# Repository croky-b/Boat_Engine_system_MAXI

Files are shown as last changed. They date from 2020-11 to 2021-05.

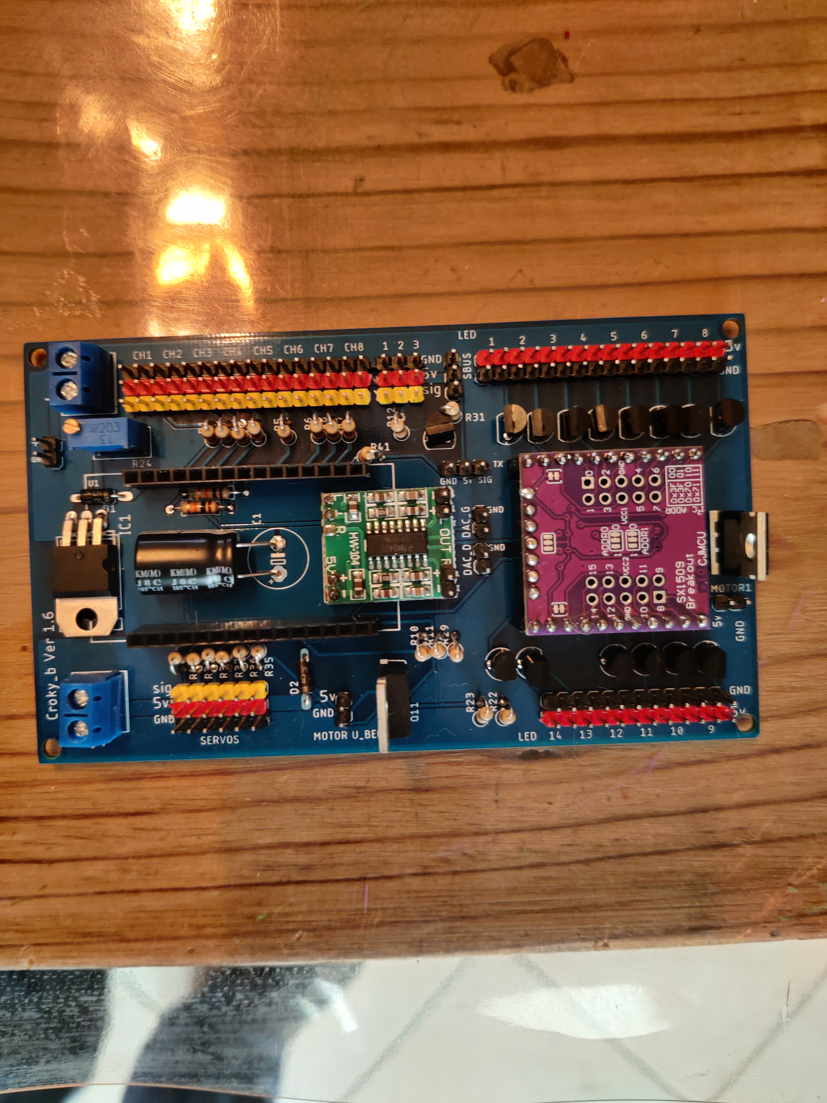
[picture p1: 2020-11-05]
IMG_20201025_121146.jpg

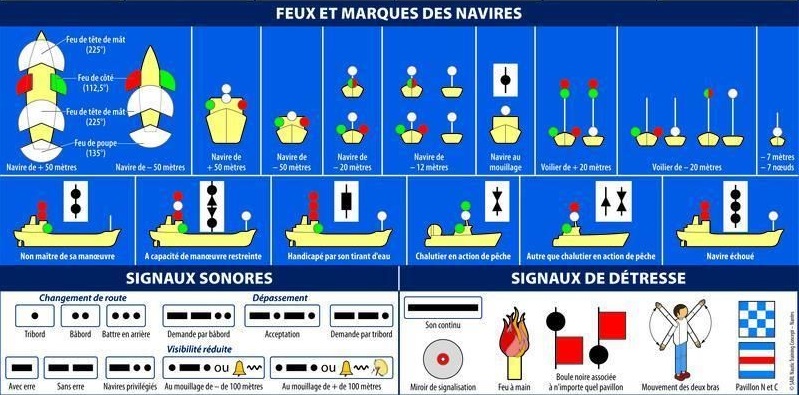
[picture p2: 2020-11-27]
Config 5.7/Fichiers/feux et sons.jpg

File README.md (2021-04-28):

# This is an Arduino RC engine sound & light & Servo controller for ESP32
Adaptation du projet de :https://github.com/TheDIYGuy999/Rc_Engine_Sound_ESP32
pour une utilisation "bateau" 

## Eratta : R29 = 10K 

## Version :
### version 5.7:
fonction special led 
multiswitch 
les fichiers des multiswitch arriveron bientot
### version 5.5:
- Integration des séquences 
### version 5.3:
- Bug sur VOSPER sound fixed 
### version 5.2:
- 
### Version 5.1:
- Configuration par HTML
### Version 5.0:
-

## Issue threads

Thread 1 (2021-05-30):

Config and error at Compiler

aexeler, 2021-05-30:
Hi Croky-b,
i found yout great Project and will build it.
ill try to understand your Config tool, so first i test it with no Action or LED fuction.
So i only select in the Generalconfig:

Son Moteur: PT Boat
AIR STARTER yes
Engine ON/OFF
Manuel  7 Ch
Start SounBoard Sound: Corne de brume

rest as default

Create Setup file and save, copy the 1-Setup.h to the Project folder and compile:

get this error

Boat_Engine_system_MAXI\sounds\boat\AuxSound\Long_blast1.h:1:1: error: stray '\357' in program

Boat_Engine_system_MAXI\sounds\boat\AuxSound\Long_blast1.h:1:1: error: stray '\273' in program

Boat_Engine_system_MAXI\sounds\boat\AuxSound\Long_blast1.h:1:1: error: stray '\277' in program

exit status 1

Find out that i have change in the Action 3 (not selectet) the "Corne brume 1" to "Corne brume 2" and the compile works!
So Sound up at Start and engine runs!!!

Try some Action, but now any new Action (Sound) e.g. Cloche will work.

May you can explane me your Config-Tool.
Best Regards
Andreas Exeler

PS, i need a huge (5000PS) Diesel Engine Sound (i have a Happy Hunter from Robbe)
The TheDIYGuy999, Martin, has told me to look at your Project, because i have no Trucks.

croky-b, 2021-05-30:
Hello Send me your setup file CédricLe 30 mai 2021 13:18, aexeler ***@***.***> a écrit :
Hi Croky-b,
i found yout great Project and will build it.
ill try to understand your Config tool, so first i test it with no Action or LED fuction.
So i only select in the Generalconfig:
Son Moteur: PT Boat
AIR STARTER yes
Engine ON/OFF
Manuel  7 Ch
Start SounBoard Sound: Corne de brume
rest as default
Create Setup file and save, copy the 1-Setup.h to the Project folder and compile:
get this error
Boat_Engine_system_MAXI\sounds\boat\AuxSound\Long_blast1.h:1:1: error: stray '\357' in program
Boat_Engine_system_MAXI\sounds\boat\AuxSound\Long_blast1.h:1:1: error: stray '\273' in program
Boat_Engine_system_MAXI\sounds\boat\AuxSound\Long_blast1.h:1:1: error: stray '\277' in program
exit status 1
Find out that i have change in the Action 3 (not selectet) the "Corne brume 1" to "Corne brume 2" and the compile works!
So Sound up at Start and engine runs!!!
Try some Action, but now any new Action (Sound) e.g. Cloche will work.
May you can explane me your Config-Tool.
Best Regards
Andreas Exeler
PS, i need a huge (5000PS) Diesel Engine Sound (i have a Happy Hunter from Robbe)
The TheDIYGuy999, Martin, has told me to look at your Project, because i have no Trucks.

—You are receiving this because you are subscribed to this thread.Reply to this email directly, view it on GitHub, or unsubscribe.

croky-b, 2021-05-30:
Boat_Engine_system_MAXI\sounds\boat\AuxSound\Long_blast1.h:1:1: error: stray '\357' in program

For this check if the sound is in the folder

croky-b, 2021-05-30:
Contact me on my email

aexeler, 2021-05-30:
Hi,
i am sorry, but i cant see your email, sorry.
[Setup.txt](https://github.com/croky-b/Boat_Engine_system_MAXI/files/6566768/Setup.txt)
The long_blast1.h is in the folder.

What kind of Multiswitch you prefer?
Will this work?
[https://shop.cp-elektronik.de/Sender-erweitern/16-Kanal-Encoder-Nautic-Schaltbaustein-MC-15-u-ae::105.html](url)
( i have a MC-19 with Spektrum 2.4 GHz Transmitter)

Greets and thanks for help!
Andreas

croky-b, 2021-05-30:
Can you sens me the setup from Arduino, It s the recap fileLe 30 mai 2021 21:07, aexeler ***@***.***> a écrit :
Hi,
i am sorry, but i cant see your email, sorry.
Setup.txt
The long_blast1.h is in the folder.
What kind of Multiswitch you prefer?
Will this work?
https://shop.cp-elektronik.de/Sender-erweitern/16-Kanal-Encoder-Nautic-Schaltbaustein-MC-15-u-ae::105.html
( i have a MC-19 with Spektrum 2.4 GHz Transmitter)
Greets and thanks for help!
Andreas

—You are receiving this because you commented.Reply to this email directly, view it on GitHub, or unsubscribe.

aexeler, 2021-05-30:
Hi,
The setup.txt in my last post is the recap file.
Thanks for help.
Andreas

croky-b, 2021-05-30:
For the multi Switch http://www.bricodx.fr/articles/3-electronique/16-commande-multifonctions/The type 1 us for the simple versionThe type 2 is for the optocoupler versionLe 30 mai 2021 21:07, aexeler ***@***.***> a écrit :
Hi,
i am sorry, but i cant see your email, sorry.
Setup.txt
The long_blast1.h is in the folder.
What kind of Multiswitch you prefer?
Will this work?
https://shop.cp-elektronik.de/Sender-erweitern/16-Kanal-Encoder-Nautic-Schaltbaustein-MC-15-u-ae::105.html
( i have a MC-19 with Spektrum 2.4 GHz Transmitter)
Greets and thanks for help!
Andreas

—You are receiving this because you commented.Reply to this email directly, view it on GitHub, or unsubscribe.

croky-b, 2021-05-30:
Yes it is the setup recapSend me  setup.h Sorry for m'y bad englishCédricLe 30 mai 2021 21:07, aexeler ***@***.***> a écrit :
Hi,
i am sorry, but i cant see your email, sorry.
Setup.txt
The long_blast1.h is in the folder.
What kind of Multiswitch you prefer?
Will this work?
https://shop.cp-elektronik.de/Sender-erweitern/16-Kanal-Encoder-Nautic-Schaltbaustein-MC-15-u-ae::105.html
( i have a MC-19 with Spektrum 2.4 GHz Transmitter)
Greets and thanks for help!
Andreas

—You are receiving this because you commented.Reply to this email directly, view it on GitHub, or unsubscribe.

croky-b, 2021-05-30:
The stray error is due to a bad character but at home I do not have itI use the Arduino version 1.8.12Le 30 mai 2021 21:07, aexeler ***@***.***> a écrit :
Hi,
i am sorry, but i cant see your email, sorry.
Setup.txt
The long_blast1.h is in the folder.
What kind of Multiswitch you prefer?
Will this work?
https://shop.cp-elektronik.de/Sender-erweitern/16-Kanal-Encoder-Nautic-Schaltbaustein-MC-15-u-ae::105.html
( i have a MC-19 with Spektrum 2.4 GHz Transmitter)
Greets and thanks for help!
Andreas

—You are receiving this because you commented.Reply to this email directly, view it on GitHub, or unsubscribe.

aexeler, 2021-05-30:
Hi,
my english is not better. ;-)
hier the 1-setup.h

Will the type 2 with optocoupler work with your Boat Engine System?

Greets
Andreas

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

aexeler, 2021-05-30:
cant attach  a .h file, so i rename the .h to .txt
the 1-Setup.txt is the 1-Setup.h
[1-Setup.txt](https://github.com/croky-b/Boat_Engine_system_MAXI/files/6566816/1-Setup.txt)

croky-b, 2021-05-30:
define ACTION3CH 0
No Channel assigned to action 3
The action 3 it is for the fog mode

croky-b, 2021-05-30:
The fog mode , played sound automatically
Example: the bell when the anchor is at the bottom

croky-b, 2021-05-30:
Will the type 2 with optocoupler work with your Boat Engine System?

Yes i use it on my futaba fc16
I'll upload the modified code for my project

aexeler, 2021-05-30:
Ah, ok.
So i have to use a other action and try it.
The type 2 with optocoupler on bricodx will work with your system?
Greets
Andreas

aexeler, 2021-05-30:
Ok, i will have a look at the type 2 for my mc19
Thanks

aexeler, 2021-05-30:
Need i Chance the code for the Arduino Mini in the Transmitter?

croky-b, 2021-05-30:
Yes a litle. It is possible to have 14 or 16 Channel to one Channel

And the pulse start to 2

croky-b, 2021-05-30:
I fixed the fog mode bell bug
That's why the bell rings at home

aexeler, 2021-05-30:
have you the code for the Transmitter?
i am not sure that i can change it right.

croky-b, 2021-05-30:
I upload tomorrow the code

aexeler, 2021-05-30:
Thanks,
Will try tomorrow a new Version with more Actions on the Controller

croky-b, 2021-05-30:
Action 1: special lamps for fishing vessels (red on white lights)

Action 2 for anchor

Action 3 fog mode

Action 4 manoeuvre
3 sound for reversing
2 for left

Action 5 warning
Overtaking from the left

Action 6 machine gun
Action 7 cannon

Action 8 alarm

Action 9 night mode

Action 10 lighting of lamps

Action 11
Plays a sound
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
croky-b, 2022-03-30:
I fixed the bug of shorthorn1

croky-b, 2022-03-30:
changes  PULSWIDTH_DEBUG
by that one

#ifdef PULSWIDTH_DEBUG
if (millis() - printMillis > 300) // Print the data every 300ms
{
printMillis = millis();
if (Init){
Serial.print("SOUNDBOARD START = OK");}
else{Serial.print("SOUNDBOARD START = WAIT!!");}
Serial.println(" ");
if(engineState==0){Serial.print("Motor = OFF");}

else if (engineState==1){Serial.print("Motor = AIRSTART");}
else if (engineState==2){Serial.print("Motor = START");}
else if (engineState==3){Serial.print("Motor = ON");}
else if (engineState==4){Serial.print("Motor = SHUTDOWN");}
Serial.println(" ");

Serial.print("pulseWidth[MULTI_1_CH-1] :");
Serial.println(pulseWidth[MULTI_1_CH-1]);

Serial.print("Act1 :");
Serial.println(Act1);

Serial.print("Act1 :");
Serial.println(Act2);

Serial.print("Act3 :");
Serial.println(Act3);

Serial.print("Act4 :");
Serial.println(Act4);

Serial.print("Act5 :");
Serial.println(Act5);

Serial.print("Act6 :");
Serial.println(Act6);

Serial.print("Act7 :");
Serial.println(Act7);

Serial.print("Act8 :");
Serial.println(Act8);

Serial.print("Fishing :");
Serial.println(Fishing);

Serial.print("DIRECTION :");
Serial.println(pulseWidth[steeringCh - 1]);

Serial.print("PROFONDEUR :");
Serial.println(pulseWidth[ElCh - 1]);

Serial.print("GAZ :");
Serial.println(pulseWidth[thrustCh - 1]);

Serial.print("AILLERONS :");
Serial.println(pulseWidth[AilCh-1]);
Serial.print("CH5 :");
Serial.println(pulseWidth[4]);
Serial.print("CH6 :");
Serial.println(pulseWidth[5]);
Serial.print("CH7 :");
Serial.println(pulseWidth[6]);
Serial.print("CH8 :");
Serial.println(pulseWidth[7]);
Serial.print("CH9 :");
Serial.println(pulseWidth[8]);
Serial.print("CH10 :");
Serial.println(pulseWidth[9]);
Serial.print("CH11 :");
Serial.println(pulseWidth[10]);
Serial.print("CH14 :");
Serial.println(pulseWidth[13]);

Serial.println("");

}
#endif

croky-b, 2022-03-30:
When you started the engine?
If yes
Use the action 9 it allows to light the leds chosen when the engine has started

aexeler, 2022-03-30:
Hi,
no Action is set, only the gerneralconfig is set,
try to compile but get error:

Sound:3136:0: error: unterminated #ifdef
  #ifdef ACTION11A_ENABLE
 ^
exit status 1
unterminated #ifdef

croky-b, 2022-03-30:
I am fixing quite a few errors but I lost a lot of files due to pc crash

aexeler, 2022-03-30:
oh,
thats bad,
i am sorry, so many work for me.
take the time as you need, no problem
thanks for help!

croky-b, 2022-03-30:
This weekend I will make a configuration that works at home and I transmit it to you

aexeler, 2022-03-31:
that would be great!

aexeler, 2022-04-01:
Hi,
i try some diff. settings and found some "Bugs".
The Channel for the Sequence1 and 2 are in the save file the same (eg. ch10), but in the html are set on Ch9 and 10.
The Action9 LED will work (so the SX1509 is online!) when the Engine start manual and the Action 9 is setup with an switch.
The led came on the engine start but not on the selectet switch.
May it helps.

Greets
Andreas

croky-b, 2022-04-01:
Ok I fixed the sequence bug
Good news that the sx1509 works
There must be a bug in the multiswitch code
I found some for type1, I'm trying to fix them

aexeler, 2022-04-01:
Hi,

top, thanks!

Is there a change to get an “import” for the config-file in the html-configurator?

So, every new open, I must setup all pages to generate a new config.

(at the moment I test a lot)

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

croky-b, 2022-04-01:
#include "XT_DAC_Audio.h"

//______________________________________________________________________________
//-------------------------------VOLUME----------------------------------
//_______________________________________________________________________________

#define ANCOR_VOL 127
#define SHORT_VOL 127
#define LONG_VOL 127
#define GUN_VOL 127
#define AAGUN_VOL 127
#define LONG_VOL 127
#define ALARM1_VOL 127
#define ALARM2_VOL 127
#define BELL_VOL 127
#define SEAGULL_VOL 127
#define AMBIENT_VOL 127
#define TWELVE1_VOL 127
#define TWELVE2_VOL 127
#define TWELVE3_VOL 127
#define ELEVEN1_VOL 127
#define ELEVEN2_VOL 127
#define ELEVEN3_VOL 127
#define
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

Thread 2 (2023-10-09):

Compilation Problem.

chris27940, 2023-10-09:
Hi, good evening.
I try to finish my boat engine system but i have one error when i try to compile the sketch : text section exceeds available space in board Le croquis utilise 2203490 octets (168%) de l'espace de stockage de programmes. Le maximum est de 1310720 octets;
Do you known what the problem with the sketch ? Do i have to change board config ?
Thanks. Regards, Christophe.

croky-b, 2023-10-09:
hi
in arduino ide
TOOL>>partition Scheme>>>Hudge app

chris27940, 2023-10-21:
Thanks a lot. It's working now.

chris27940, 2023-10-21:
Good morning, i have another question. Before compliling, i have to open Config_Croky_b and save only setup file ? What is the fonction "create INO file" ? Thanks.

croky-b, 2023-10-21:
Créât ino file is for the servo sequencer

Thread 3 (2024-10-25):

Broken program ,pleas Help

paegas123, 2024-10-25:
Hello, I'm trying to start this cool project, unfortunately I'm not succeeding at all. The program is normally compiled and uploaded to the ESP32. I have only the amplifier connected to PIO25,26 and the input from the receiver to PIO14 as throttle control. After uploading the ESP32 firmware, it does nothing and does not respond. It can be seen on the serial monitor that it is not doing anything. That is, during HW restart, it will print the restart log, but nothing else. There is no sound coming from the speaker even when the gas is applied. Engine start is set to AUTO. In my opinion, in ESP32 the program won't run at all for some reason. The ESP32 is brand new and works normally with another project. Please help

croky-b, 2025-01-27:
sorry for the late reply, I didn't get a notification

i realized that the code was only compatible with version 1.0.5 of expressif
system in the esp32 card manager, already do a test like that

it's been a long time since i worked on this code, i forgot a lot of things about how it works, i hope this will solve your problem

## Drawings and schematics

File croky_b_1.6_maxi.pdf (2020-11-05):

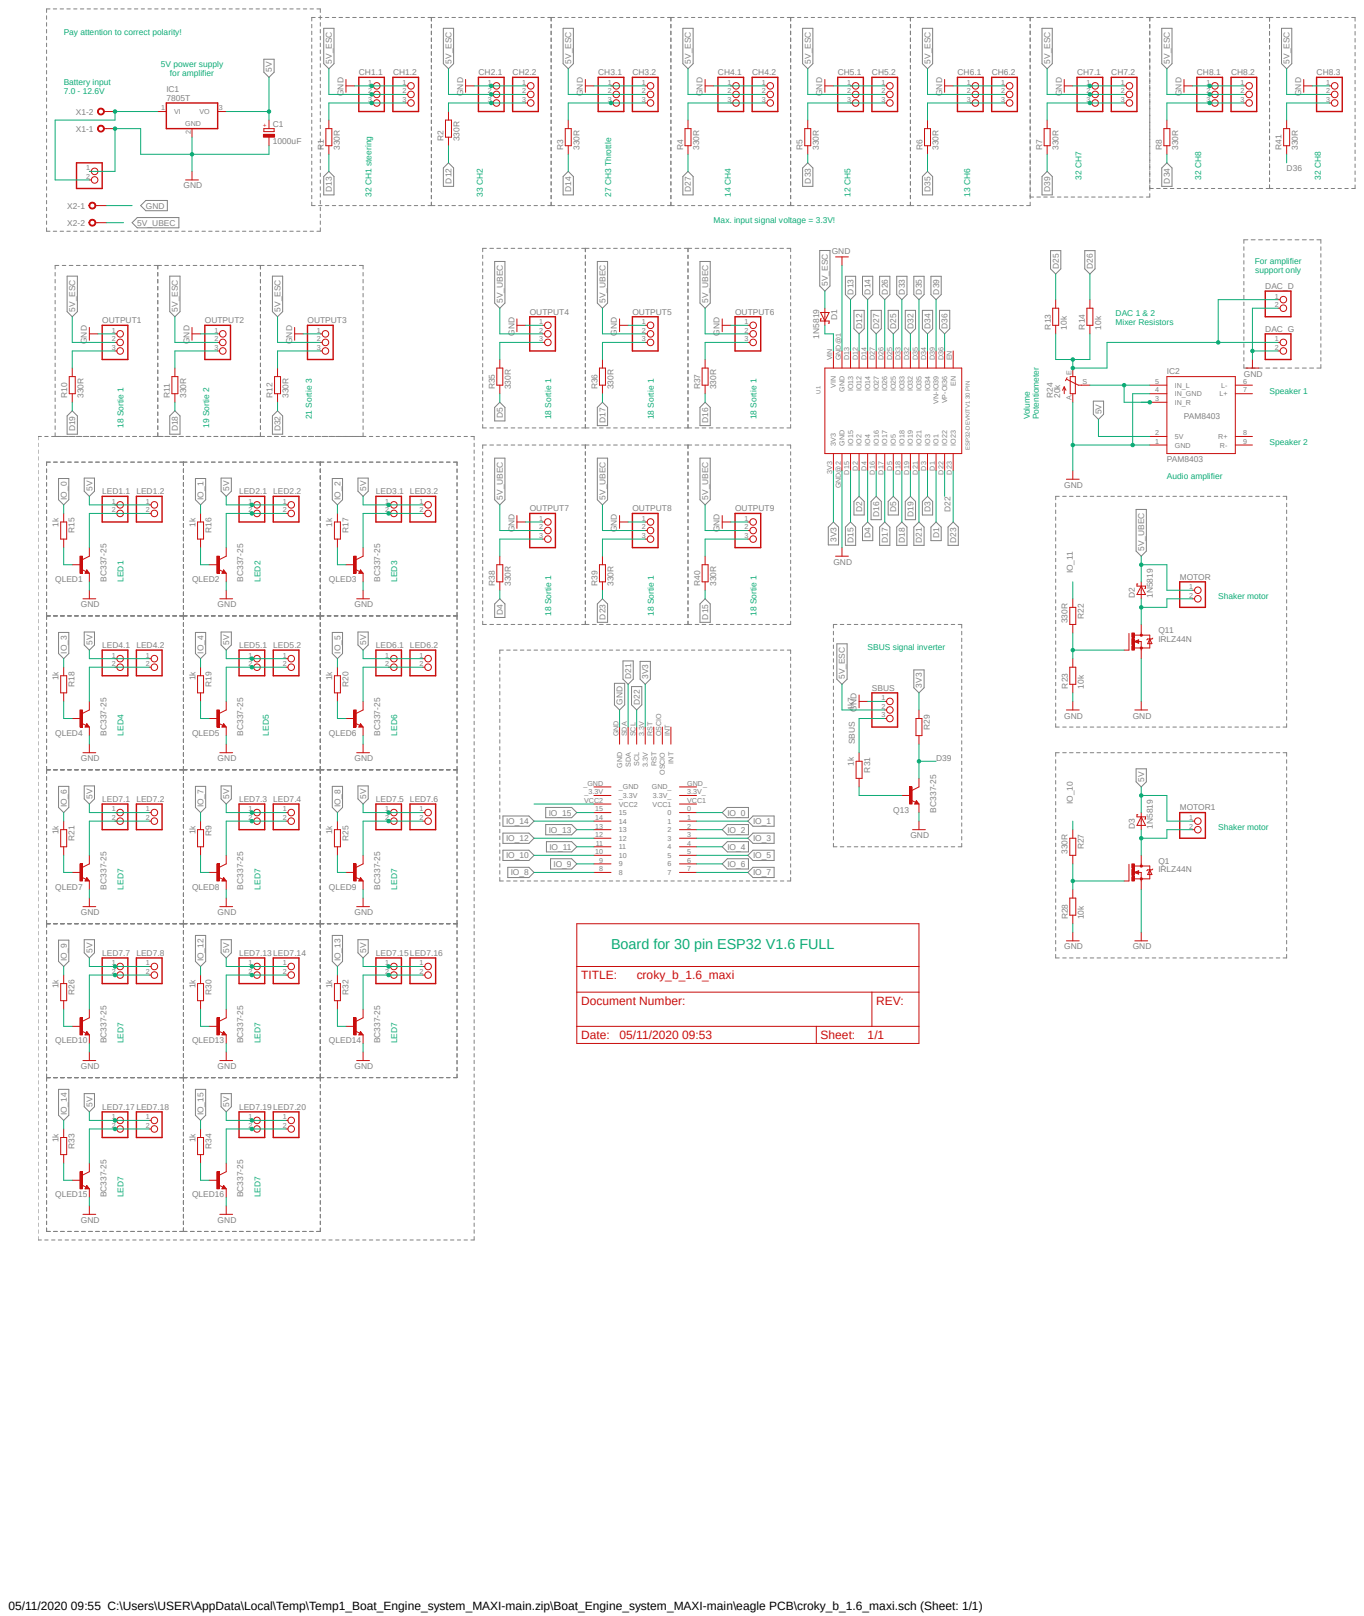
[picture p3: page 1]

Pay attention to correct polarity!

Max. input signal voltage = 3.3V!

IO23 D23 EN EN VP-OI36 D36 VN-IO39 D39 IO34 D34 IO35 D35 IO32 D32 IO33 D33 IO25 D25 IO26 D26 IO27 D27 IO14 D14 IO12 D12 IO13 D13 GND GND@1 VIN VIN GND GND@2

Board for 30 pin ESP32 V1.6 FULL

Document Number: | REV:

Date: 05/11/2020 09:53 | Sheet: 1/1

05/11/2020 09:55 C:\Users\USER\AppData\Local\Temp\Temp1_Boat_Engine_system_MAXI-main.zip\Boat_Engine_system_MAXI-main\eagle PCB\croky_b_1.6_maxi.sch (Sheet: 1/1)

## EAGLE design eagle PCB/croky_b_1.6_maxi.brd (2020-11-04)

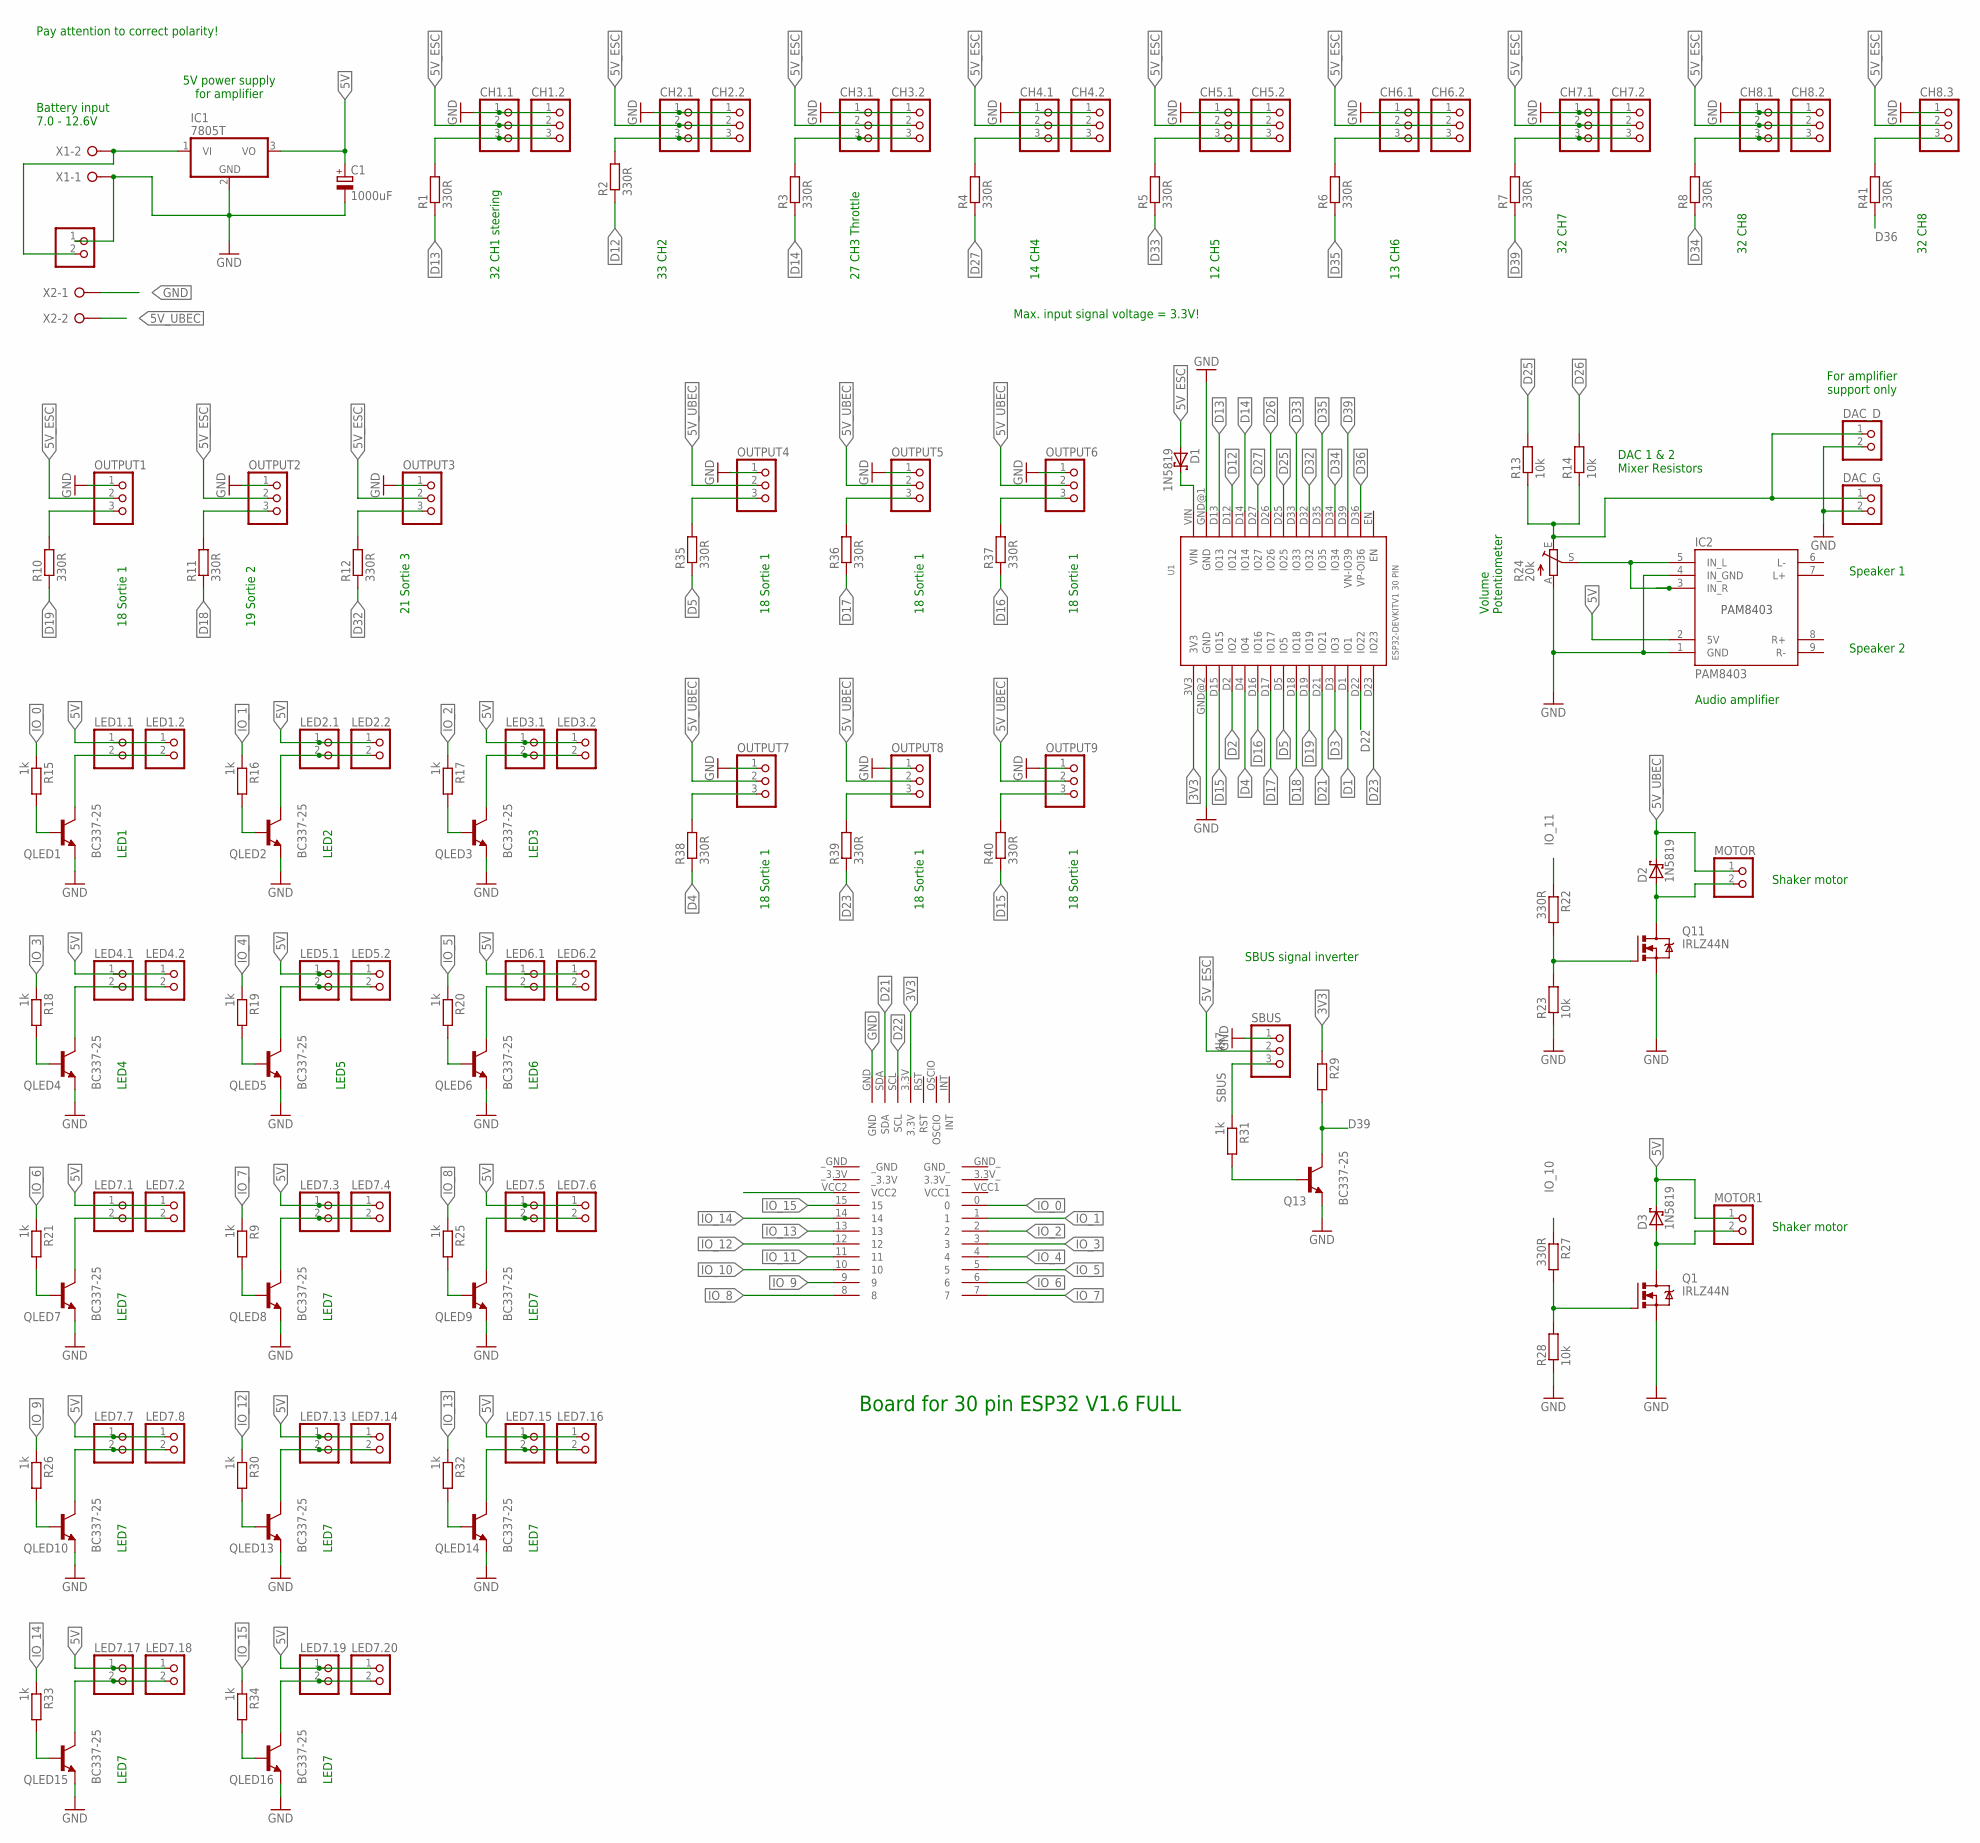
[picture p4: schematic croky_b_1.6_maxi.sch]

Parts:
C1: 1000uF; E5-10,5
CH1.1, CH1.2, CH2.1, CH2.2, CH3.1, CH3.2, CH4.1, CH4.2, CH5.1, CH5.2, CH6.1, CH6.2, CH7.1, CH7.2, CH8.1, CH8.2, CH8.3: PINHD-1X3; 1X03
D1, D2, D3: 1N5819; DO35-7
DAC_D: PINHD-1X2; 1X02
DAC_G: PINHD-1X2; 1X02
IC1: 7805T; TO220H
IC2: PAM8403
LED1.1, LED1.2, LED2.1, LED2.2, LED3.1, LED3.2, LED4.1, LED4.2, LED5.1, LED5.2, LED6.1, LED6.2, LED7.1, LED7.2, LED7.3, LED7.4, LED7.5, LED7.6, LED7.7, LED7.8, LED7.13, LED7.14, LED7.15, LED7.16, LED7.17, LED7.18, LED7.19, LED7.20: PINHD-1X2; 1X02
MOTOR, MOTOR1, MOTOR2: PINHD-1X2; 1X02
OUTPUT1, OUTPUT2, OUTPUT3, OUTPUT4, OUTPUT5, OUTPUT6, OUTPUT7, OUTPUT8, OUTPUT9: PINHD-1X3; 1X03
Q1, Q11: IRLZ44N; TO220BV
Q13: BC337-25; TO92
QLED1, QLED2, QLED3, QLED4, QLED5, QLED6, QLED7, QLED8, QLED9, QLED10, QLED13, QLED14, QLED15, QLED16: BC337-25; TO92
R1, R2, R3, R4, R5, R6, R7, R8, R10, R11, R12, R22, R27, R35, R36, R37, R38, R39, R40, R41: 330R; 0207/2V
R9, R15, R16, R17, R18, R19, R20, R21, R25, R26, R30, R31, R32, R33, R34: 1k; 0207/2V
R13, R14: 10k; 0207/10
R23, R28: 10k; 0207/2V
R24: 20k; S64W
R29: 4k7; 0207/2V
SBUS: PINHD-1X3; 1X03
U1: ESP32DEVKITV1; ESP32-DEVKITV1
U$1: TEST
X1, X2: W237-02P; W237-132

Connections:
3V3: R29.1, U1.3V3, U$1.3.3V
5V: C1.+, D3.C, IC1.3 (VO), IC2.2 (5V), LED1.1.1, LED1.2.1, LED2.1.1, LED2.2.1, LED3.1.1, LED3.2.1, LED4.1.1, LED4.2.1, LED5.1.1, LED5.2.1, LED6.1.1, LED6.2.1, LED7.1.1, LED7.2.1, LED7.3.1, LED7.4.1, LED7.5.1, LED7.6.1, LED7.7.1, LED7.8.1, LED7.13.1, LED7.14.1, LED7.15.1, LED7.16.1, LED7.17.1, LED7.18.1, LED7.19.1, LED7.20.1, MOTOR1.1
5V_ESC: CH1.1.2, CH1.2.2, CH2.1.2, CH2.2.2, CH3.1.2, CH3.2.2, CH4.1.2, CH4.2.2, CH5.1.2, CH5.2.2, CH6.1.2, CH6.2.2, CH7.1.2, CH7.2.2, CH8.1.2, CH8.2.2, CH8.3.2, D1.A, OUTPUT1.2, OUTPUT2.2, OUTPUT3.2, SBUS.2
5V_UBEC: D2.C, MOTOR.1, OUTPUT4.2, OUTPUT5.2, OUTPUT6.2, OUTPUT7.2, OUTPUT8.2, OUTPUT9.2, X2.2
-: LED2.1.2, LED2.2.2, QLED2.3 (C)
--: LED3.1.2, LED3.2.2, QLED3.3 (C)
BAT+: IC1.1 (VI), MOTOR2.2, X1.2
D1: U1.D1 (IO1)
D2: U1.D2 (IO2)
D3: U1.D3 (IO3)
D4: R38.1, U1.D4 (IO4)
D5: R35.1, U1.D5 (IO5)
D12: R2.1, U1.D12 (IO12)
D13: R1.1, U1.D13 (IO13)
D14: R3.1, U1.D14 (IO14)
D15: R40.1, U1.D15 (IO15)
D16: R37.1, U1.D16 (IO16)
D17: R36.1, U1.D17 (IO17)
D18: R11.1, U1.D18 (IO18)
D19: R10.1, U1.D19 (IO19)
D21: U1.D21 (IO21), U$1.SDA
D22: U1.D22 (IO22), U$1.SCL
D23: R39.1, U1.D23 (IO23)
D25: R13.2, U1.D25 (IO25)
D26: R14.2, U1.D26 (IO26)
D27: R4.1, U1.D27 (IO27)
D32: R12.1, U1.D32 (IO32)
D33: R5.1, U1.D33 (IO33)
D34: R8.1, U1.D34 (IO34)
D35: R6.1, U1.D35 (IO35)
D36: R41.1, U1.D36 (VP-OI36)
D39: Q13.3 (C), R7.1, R29.2, U1.D39 (VN-IO39)
GND: C1.-, CH1.1.1, CH1.2.1, CH2.1.1, CH2.2.1, CH3.1.1, CH3.2.1, CH4.1.1, CH4.2.1, CH5.1.1, CH5.2.1, CH6.1.1, CH6.2.1, CH7.1.1, CH7.2.1, CH8.1.1, CH8.2.1, CH8.3.1, DAC_D.2, DAC_G.2, IC1.2 (GND), IC2.1 (GND), IC2.4 (IN_GND), MOTOR2.1, OUTPUT1.1, OUTPUT2.1, OUTPUT3.1, OUTPUT4.1, OUTPUT5.1, OUTPUT6.1, OUTPUT7.1, OUTPUT8.1, OUTPUT9.1, Q1.S, Q11.S, Q13.1 (E), QLED1.1 (E), QLED2.1 (E), QLED3.1 (E), QLED4.1 (E), QLED5.1 (E), QLED6.1 (E), QLED7.1 (E), QLED8.1 (E), QLED9.1 (E), QLED10.1 (E), QLED13.1 (E), QLED14.1 (E), QLED15.1 (E), QLED16.1 (E), R23.1, R24.A, R28.1, SBUS.1, U1.GND@1 (GND), U1.GND@2 (GND), U$1.GND, X1.1, X2.1
IO_0: R15.1, U$1.0
IO_1: R16.1, U$1.1
IO_2: R17.1, U$1.2
IO_3: R18.1, U$1.3
IO_4: R19.1, U$1.4
IO_5: R20.1, U$1.5
IO_6: R21.1, U$1.6
IO_7: R9.1, U$1.7
IO_8: R25.1, U$1.8
IO_9: R26.1, U$1.9
IO_10: R27.1, U$1.10
IO_11: R22.1, U$1.11
IO_12: R30.1, U$1.12
IO_13: R32.1, U$1.13
IO_14: R33.1, U$1.14
IO_15: R34.1, U$1.15
unnamed: IC2.3 (IN_R), IC2.5 (IN_L), R24.S
unnamed: CH6.1.3, CH6.2.3, R6.2
unnamed: Q11.G, R22.2, R23.2
unnamed: CH5.1.3, CH5.2.3, R5.2
unnamed: CH4.1.3, CH4.2.3, R4.2
unnamed: CH7.1.3, CH7.2.3, R7.2
unnamed: CH3.1.3, CH3.2.3, R3.2
unnamed: D1.C, U1.VIN
unnamed: CH1.1.3, CH1.2.3, R1.2
unnamed: OUTPUT1.3, R10.2
unnamed: OUTPUT2.3, R11.2
unnamed: OUTPUT3.3, R12.2
unnamed: CH2.1.3, CH2.2.3, R2.2
unnamed: D2.A, MOTOR.2, Q11.D
unnamed: QLED1.2 (B), R15.2
unnamed: QLED6.2 (B), R20.2
unnamed: LED1.1.2, LED1.2.2, QLED1.3 (C)
unnamed: LED6.1.2, LED6.2.2, QLED6.3 (C)
unnamed: DAC_D.1, DAC_G.1, R13.1, R14.1, R24.E
unnamed: QLED8.2 (B), R9.2
unnamed: QLED3.2 (B), R17.2
unnamed: LED7.3.2, LED7.4.2, QLED8.3 (C)
unnamed: QLED2.2 (B), R16.2
unnamed: QLED9.2 (B), R25.2
unnamed: LED7.5.2, LED7.6.2, QLED9.3 (C)
unnamed: QLED7.2 (B), R21.2
unnamed: LED7.1.2, LED7.2.2, QLED7.3 (C)
unnamed: QLED4.2 (B), R18.2
unnamed: LED4.1.2, LED4.2.2, QLED4.3 (C)
unnamed: QLED10.2 (B), R26.2
unnamed: LED7.7.2, LED7.8.2, QLED10.3 (C)
unnamed: Q1.G, R27.2, R28.2
unnamed: D3.A, MOTOR1.2, Q1.D
unnamed: QLED5.2 (B), R19.2
unnamed: LED5.1.2, LED5.2.2, QLED5.3 (C)
unnamed: Q13.2 (B), R31.2
unnamed: CH8.3.3, R41.2
unnamed: QLED13.2 (B), R30.2
unnamed: CH8.1.3, CH8.2.3, R8.2
unnamed: LED7.13.2, LED7.14.2, QLED13.3 (C)
unnamed: QLED14.2 (B), R32.2
unnamed: LED7.15.2, LED7.16.2, QLED14.3 (C)
unnamed: QLED15.2 (B), R33.2
unnamed: LED7.17.2, LED7.18.2, QLED15.3 (C)
unnamed: QLED16.2 (B), R34.2
unnamed: LED7.19.2, LED7.20.2, QLED16.3 (C)
unnamed: OUTPUT4.3, R35.2
unnamed: OUTPUT5.3, R36.2
unnamed: OUTPUT6.3, R37.2
unnamed: OUTPUT7.3, R38.2
unnamed: OUTPUT8.3, R39.2
unnamed: OUTPUT9.3, R40.2
SBUS: R31.1, SBUS.3

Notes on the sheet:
Speaker 1
Speaker 2
13 CH6
12 CH5
14 CH4
27 CH3 Throttle
33 CH2
32 CH1 steering
18 Sortie 1
19 Sortie 2
21 Sortie 3
DAC 1 & 2 Mixer Resistors
Audio amplifier
Volume Potentiometer
5V power supply for amplifier
Battery input 7.0 - 12.6V
Board for 30 pin ESP32 V1.6 FULL
Shaker motor
LED1
LED6
LED3
LED2
LED7
LED4
LED5
For amplifier support only
Pay attention to correct polarity!
Max. input signal voltage = 3.3V!
32 CH7
32 CH8
SBUS signal inverter

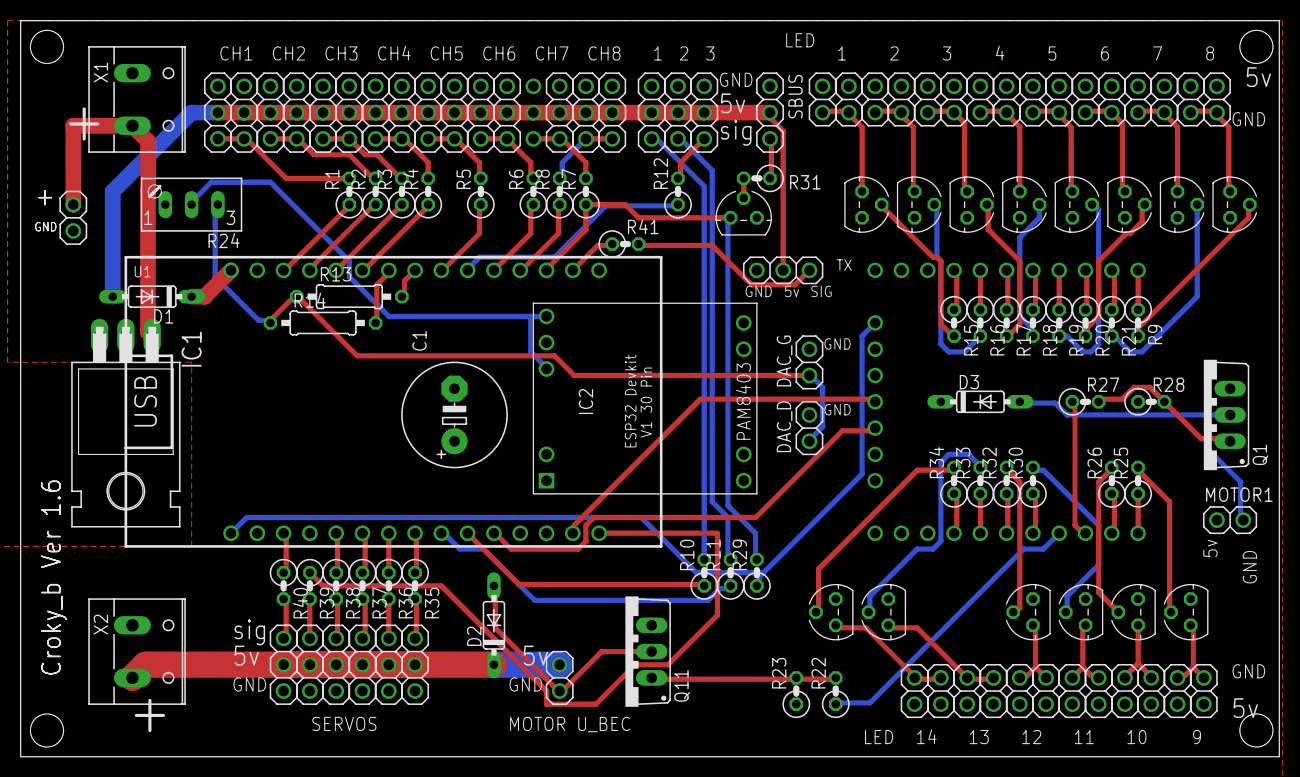
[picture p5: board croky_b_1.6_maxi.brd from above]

Board: 2 copper layers, 121.6 x 71.1 mm, 128 parts (1 on the bottom side), 99 nets.

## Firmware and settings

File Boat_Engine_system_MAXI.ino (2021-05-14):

/* RC engine sound & LED controller for Arduino ESP32. Written by TheDIYGuy999
    Based on the code for ATmega 328: https://github.com/TheDIYGuy999/Rc_Engine_Sound
    modified for boat by croky_b for boat

 *  ***** ESP32 CPU frequency must be set to 240MHz! *****

   
*/

const float codeVersion = 5.7; // Software revision.

//
// =======================================================================================================
// SETTINGS (ADJUST THEM BEFORE CODE UPLOAD)
// =======================================================================================================
//

#include "2-Sound_config.h"
#include "1-Setup.h"
#include "driver/rmt.h"


// Make sure to remove -master from your sketch folder name

// DEBUG options can slow down the playback loop! Only comment them out for debugging
//#define PULSWIDTH_DEBUG //
//#define DEBUG // uncomment it for general debugging informations
//#define SBUS_DEBUG // uncomment it to debug the SBUS command interface on pin 36
//#define ESC_DEBUG // uncomment it to debug the ESC control

// TODO = Things to clean up!

//
// =======================================================================================================
// LIRBARIES & HEADER FILES (TABS ABOVE)
// =======================================================================================================
//



// Libraries (you have to install all of them)
#include <statusLED.h> // https://github.com/TheDIYGuy999/statusLED <<------- Install the newest version!
#include <SBUS.h>     // https://github.com/TheDIYGuy999/SBUS you need to install my fork of this library!
#include <SparkFunSX1509.h> //use my fork of this library (modified version)
#include <SlowMotionServo.h>//use my fork of this library (modified version)
#include <Servo_MCPWM.h>
#include <PWMTrigger.h>
#include "XT_DAC_Audio.h"
#include <ScheduleTable.h>
#ifdef PCA_OPTION
#include <Adafruit_PWMServoDriver.h>
#endif
//
// =======================================================================================================
// PIN ASSIGNMENTS & GLOBAL VARIABLES (Do not play around here)
// =======================================================================================================
//
// Pin assignment and wiring instructions

// ------------------------------------------------------------------------------------
// Use a 330Ohm resistor in series with all I/O pins! allows to drive LED directly and
// provides short circuit protection.
// ------------------------------------------------------------------------------------

#define RMT_TICK_PER_US 1
// determines how many clock cycles one "tick" is
// [1..255], source is generally 80MHz APB clk
#define RMT_RX_CLK_DIV (80000000/RMT_TICK_PER_US/1000000)
// time before receiver goes idle
#define RMT_RX_MAX_US 3500

uint32_t maxPwmRpmPercentage = 400; // Limit required to prevent controller fron crashing @ high engine RPM



#define RECEIVER_CHANNELS_NUM 8
const uint8_t RECEIVER_CHANNELS[RECEIVER_CHANNELS_NUM] = {0, 1, 2, 3, 4, 5, 6, 7 };
const uint8_t RECEIVER_PINS[RECEIVER_CHANNELS_NUM]  = {13, 12, 14, 27, 33, 35, 39, 34};


#ifdef PPM_COMMUNICATION
#define PPM_PIN    34
#endif


#ifdef SBUS_COMMUNICATION
#define COMMAND_RX  39
//#define COMMAND_TX  36
#endif

#define PULSE_NBR 15

SMSSmooth monServo1;
//SMSLinear monServo1;
SMSSmooth monServo2;
SMSSmooth monServo3;
SMSSmooth monServo4;
SMSSmooth monServo5;
SMSSmooth monServo6;

Servo Servo1;
Servo Servo2;
Servo Servo3;
Servo Servo4;
Servo Servo5;
Servo Servo6;
Servo ANCHOR;
Servo ESC1;
Servo ESC2;
Servo ESC3;


PWMTrigger Action1;
PWMTrigger Action2;
PWMTrigger Action3;
PWMTrigger Action4;
PWMTrigger Action5;
PWMTrigger Action6;
PWMTrigger Action7;
PWMTrigger Action8;
PWMTrigger Action9;
PWMTrigger Action10;
PWMTrigger Action11A;
PWMTrigger Action11B;
PWMTrigger Action11C;
PWMTrigger Action11D;
PWMTrigger Action12;
PWMTrigger VolumeCh;



SchedTable<10> Sequence1Servo(SEQ1_DURATION);
SchedTable<10> Sequence1BServo(SEQ1B_DURATION);

SchedTable<2> Sequence1BLedPart1(SEQ1B_DURATION);
SchedTable<2> Sequence1BLedPart2(SEQ1B_DURATION);
SchedTable<2> Sequence1BLedPart3(SEQ1B_DURATION);
SchedTable<2> Sequence1BLedPart4(SEQ1B_DURATION);
SchedTable<2> Sequence1BSoundPart1(SEQ1B_DURATION);
SchedTable<2> Sequence1BSoundPart2(SEQ1B_DURATION);
SchedTable<2> Sequence1BSoundPart3(SEQ1B_DURATION);
SchedTable<2> Sequence1BSoundPart4(SEQ1B_DURATION);
SchedTable<2> Sequence1BMotorPart1(SEQ1B_DURATION);
SchedTable<2> Sequence1BMotorPart2(SEQ1B_DURATION);
SchedTable<2> Sequence1BMotorPart3(SEQ1B_DURATION);
SchedTable<2> Sequence1BMotorPart4(SEQ1B_DURATION);

SchedTable<2> Sequence1LedPart1(SEQ1_DURATION);
SchedTable<2> Sequence1LedPart2(SEQ1_DURATION);
SchedTable<2> Sequence1LedPart3(SEQ1_DURATION);
SchedTable<2> Sequence1LedPart4(SEQ1_DURATION);
SchedTable<2> Sequence1SoundPart1(SEQ1_DURATION);
SchedTable<2> Sequence1SoundPart2(SEQ1_DURATION);
SchedTable<2> Sequence1SoundPart3(SEQ1_DURATION);
SchedTable<2> Sequence1SoundPart4(SEQ1_DURATION);
SchedTable<2> Sequence1MotorPart1(SEQ1_DURATION);
SchedTable<2> Sequence1MotorPart2(SEQ1_DURATION);
SchedTable<2> Sequence1MotorPart3(SEQ1_DURATION);
SchedTable<2> Sequence1MotorPart4(SEQ1_DURATION);

SchedTable<10> Sequence2BServo(SEQ2B_DURATION);

SchedTable<2> Sequence2BLedPart1(SEQ2B_DURATION);
SchedTable<2> Sequence2BLedPart2(SEQ2B_DURATION);
SchedTable<2> Sequence2BLedPart3(SEQ2B_DURATION);
SchedTable<2> Sequence2BLedPart4(SEQ2B_DURATION);
SchedTable<2> Sequence2BSoundPart1(SEQ2B_DURATION);
SchedTable<2> Sequence2BSoundPart2(SEQ2B_DURATION);
SchedTable<2> Sequence2BSoundPart3(SEQ2B_DURATION);
SchedTable<2> Sequence2BSoundPart4(SEQ2B_DURATION);
SchedTable<2> Sequence2BMotorPart1(SEQ2B_DURATION);
SchedTable<2> Sequence2BMotorPart2(SEQ2B_DURATION);
SchedTable<2> Sequence2BMotorPart3(SEQ2B_DURATION);
SchedTable<2> Sequence2BMotorPart4(SEQ2B_DURATION);

SchedTable<10> Sequence2Servo(SEQ2_DURATION);

SchedTable<2> Sequence2LedPart1(SEQ2_DURATION);
SchedTable<2> Sequence2LedPart2(SEQ2_DURATION);
SchedTable<2> Sequence2LedPart3(SEQ2_DURATION);
SchedTable<2> Sequence2LedPart4(SEQ2_DURATION);
SchedTable<2> Sequence2SoundPart1(SEQ2_DURATION);
SchedTable<2> Sequence2SoundPart2(SEQ2_DURATION);
SchedTable<2> Sequence2SoundPart3(SEQ2_DURATION);
SchedTable<2> Sequence2SoundPart4(SEQ2_DURATION);
SchedTable<2> Sequence2MotorPart1(SEQ2B_DURATION);
SchedTable<2> Sequence2MotorPart2(SEQ2_DURATION);
SchedTable<2> Sequence2MotorPart3(SEQ2_DURATION);
SchedTable<2> Sequence2MotorPart4(SEQ2_DURATION);

SchedTable<10> Sequence6Servo(SEQ6_DURATION);
SchedTable<10> Sequence6BServo(SEQ6B_DURATION);


SchedTable<2> Sequence6BSoundPart1(SEQ6B_DURATION);
SchedTable<2> Sequence6BSoundPart2(SEQ6B_DURATION);
SchedTable<2> Sequence6BSoundPart3(SEQ6B_DURATION);
SchedTable<2> Sequence6BSoundPart4(SEQ6B_DURATION);



SchedTable<2> Sequence6SoundPart1(SEQ6_DURATION);
SchedTable<2> Sequence6SoundPart2(SEQ6_DURATION);
SchedTable<2> Sequence6SoundPart3(SEQ6_DURATION);
SchedTable<2> Sequence6SoundPart4(SEQ6_DURATION);

SchedTable<10> Sequence7BServo(SEQ7B_DURATION);


SchedTable<2> Sequence7BSoundPart1(SEQ7B_DURATION);
SchedTable<2> Sequence7BSoundPart2(SEQ7B_DURATION);
SchedTable<2> Sequence7BSoundPart3(SEQ7B_DURATION);
SchedTable<2> Sequence7BSoundPart4(SEQ7B_DURATION);

SchedTable<10> Sequence7Servo(SEQ7_DURATION);


SchedTable<2> Sequence7SoundPart1(SEQ7_DURATION);
SchedTable<2> Sequence7SoundPart2(SEQ7_DURATION);
SchedTable<2> Sequence7SoundPart3(SEQ7_DURATION);
SchedTable<2> Sequence7SoundPart4(SEQ7_DURATION);

PWMTrigger CH1;
PWMTrigger CH2;
PWMTrigger CH3;
PWMTrigger CH4;
PWMTrigger CH5;
PWMTrigger CH6;
PWMTrigger CH7;
PWMTrigger CH8;
PWMTrigger CH9;
PWMTrigger CH10;
PWMTrigger CH11;
PWMTrigger CH12;
PWMTrigger CH13;
PWMTrigger CH14;
PWMTrigger CH15;
PWMTrigger CH16;

//Optional Board
#ifdef PCA_OPTION
Adafruit_PWMServoDriver board1 = Adafruit_PWMServoDriver(PCA_ADDRESS);
#endif 

#ifdef SX1509_OPTION
SX1509 Output1;
SX1509 Output2;
SX1509 Output3;
SX1509 Output4;
SX1509 Output5;
SX1509 Output6;
SX1509 Output7;
SX1509 Output8;
SX1509 Output9;
SX1509 Output10;
SX1509 Output11;
SX1509 Output12;
SX1509 Output13;
SX1509 Output14;
SX1509 Output15;
SX1509 Output16;
#endif 

// SX1509 I2C address (set by ADDR1 and ADDR0 (00 by default):
const byte SX1509_ADDRESS = 0x3E;  // SX1509 I2C address
SX1509 Led1; // Create an SX1509 object to be used throughout
SX1509 Led2; // Create an SX1509 object to be used throughout
SX1509 Led3; // Create an SX1509 object to be used throughout
SX1509 Led4; // Create an SX1509 object to be used throughout
SX1509 Led5; // Create an SX1509 object to be used throughout
SX1509 Led6; // Create an SX1509 object to be used throughout
SX1509 Led7; // Create an SX1509 object to be used throughout
SX1509 Led8; // Create an SX1509 object to be used throughout
SX1509 Led9; // Create an SX1509 object to be used throughout
SX1509 Led10; // Create an SX1509 object to be used throughout
SX1509 Led11; // Create an SX1509 object to be used throughout
SX1509 Led12; // Create an SX1509 object to be used throughout
SX1509 Led13; // Create an SX1509 object to be used throughout
SX1509 Led14; // Create an SX1509 object to be used throughout
SX1509 Motor1; // Create an SX1509 object to be used throughout
SX1509 Motor2; // Create an SX1509 object to be used throughout




#define LED_PIN       2   // LED 2

#define DAC1    25 // connect pin25 (do not change the pin) to a 10kOhm resistor
XT_DAC_Audio_Class DacAudio(26, 1); // Create the main player class object. Use GPIO 25, one of the 2 DAC pins and timer 0//

// both outputs of the resistors above are connected together and then to the outer leg of a
// 10kOhm potentiometer. The other outer leg connects to GND. The middle leg connects to both inputs
// of a PAM8403 amplifier and allows to adjust the volume. This way, two speakers can be used.



// Status LED objects (also used for PWM shaker motor and ESC control)
// "false" = output not inversed

statusLED Led_builtin(false);

/*
#ifdef ACT1_MULTISWITCH
volatile boolean Act1Permanent =false;
#endif 

#ifdef ACT2_MULTISWITCH
volatile boolean Act2Permanent =false;
#endif 

#ifdef ACT3_MULTISWITCH
volatile boolean Act3Permanent =false;
#endif 

#ifdef ACT4_MULTISWITCH
volatile boolean Act4Permanent =false;
#endif 

#ifdef ACT6_MULTISWITCH
volatile boolean Act6Permanent =false;
#endif 

#ifdef ACT7_MULTISWITCH
volatile boolean Act7Permanent =false;
#endif 

#ifdef ACT8_MULTISWITCH
volatile boolean Act8Permanent =false;
#endif 

#ifdef ACT9_MULTISWITCH
volatile boolean Act9Permanent =false;
#endif 

#ifdef ACT10_MULTISWITCH
volatile boolean Act10Permanent =false;
#endif 
*/

#if not defined ACT1_MULTISWITCH || ACT1_MULTISWITCH_UP1 || ACT1_MULTISWITCH_UP2 || ACT1_MULTISWITCH_UP3 || ACT1_MULTISWITCH_UP4 || ACT1_MULTISWITCH_DOWN1 || ACT1_MULTISWITCH_DOWN2 || ACT1_MULTISWITCH_DOWN3 || ACT1_MULTISWITCH_DOWN4
volatile uint8_t Act1 = Action1.Pos();
#endif 
#if not defined ACT2_MULTISWITCH || ACT2_MULTISWITCH_UP1 || ACT2_MULTISWITCH_UP2 || ACT2_MULTISWITCH_UP3 || ACT2_MULTISWITCH_UP4 || ACT2_MULTISWITCH_DOWN1 || ACT2_MULTISWITCH_DOWN2 || ACT2_MULTISWITCH_DOWN3 || ACT2_MULTISWITCH_DOWN4
volatile uint8_t Act2 = 0;
#endif 
#if not defined ACT3_MULTISWITCH || ACT3_MULTISWITCH_UP1 || ACT3_MULTISWITCH_UP2 || ACT3_MULTISWITCH_UP3 || ACT3_MULTISWITCH_UP4 || ACT3_MULTISWITCH_DOWN1 || ACT3_MULTISWITCH_DOWN2 || ACT3_MULTISWITCH_DOWN3 || ACT3_MULTISWITCH_DOWN4
volatile uint8_t Act3 = Action3.Pos();
#endif 
#if not defined ACT4_MULTISWITCH || ACT4_MULTISWITCH_UP1 || ACT4_MULTISWITCH_UP2 || ACT4_MULTISWITCH_UP3 || ACT4_MULTISWITCH_UP4 || ACT4_MULTISWITCH_DOWN1 || ACT4_MULTISWITCH_DOWN2 || ACT4_MULTISWITCH_DOWN3 || ACT4_MULTISWITCH_DOWN4
volatile uint8_t Act4 = Action4.Pos();
#endif 
#if not defined ACT5_MULTISWITCH || ACT5_MULTISWITCH_UP1 || ACT5_MULTISWITCH_UP2 || ACT5_MULTISWITCH_UP3 || ACT5_MULTISWITCH_UP4 || ACT5_MULTISWITCH_DOWN1 || ACT5_MULTISWITCH_DOWN2 || ACT5_MULTISWITCH_DOWN3 || ACT5_MULTISWITCH_DOWN4
volatile uint8_t Act5 = Action5.Pos();
#endif 
#if not defined ACT6_MULTISWITCH || ACT6_MULTISWITCH_UP1 || ACT6_MULTISWITCH_UP2 || ACT6_MULTISWITCH_UP3 || ACT6_MULTISWITCH_UP4 || ACT6_MULTISWITCH_DOWN1 || ACT6_MULTISWITCH_DOWN2 || ACT6_MULTISWITCH_DOWN3 || ACT6_MULTISWITCH_DOWN4
volatile uint8_t Act6 = Action6.Pos();
#endif 
#if not defined ACT7_MULTISWITCH || ACT7_MULTISWITCH_UP1 || ACT7_MULTISWITCH_UP2 || ACT7_MULTISWITCH_UP3 || ACT7_MULTISWITCH_UP4 || ACT7_MULTISWITCH_DOWN1 || ACT7_MULTISWITCH_DOWN2 || ACT7_MULTISWITCH_DOWN3 || ACT7_MULTISWITCH_DOWN4
volatile uint8_t Act7 = Action7.Pos();
#endif 
#if not defined ACT8_MULTISWITCH || ACT8_MULTISWITCH_UP1 || ACT8_MULTISWITCH_UP2 || ACT8_MULTISWITCH_UP3 || ACT8_MULTISWITCH_UP4 || ACT8_MULTISWITCH_DOWN1 || ACT8_MULTISWITCH_DOWN2 || ACT8_MULTISWITCH_DOWN3 || ACT8_MULTISWITCH_DOWN4
volatile uint8_t Act8 = Action8.Pos();
#endif 
#if not defined ACT9_MULTISWITCH || ACT9_MULTISWITCH_UP1 || ACT9_MULTISWITCH_UP2 || ACT9_MULTISWITCH_UP3 || ACT9_MULTISWITCH_UP4 || ACT9_MULTISWITCH_DOWN1 || ACT9_MULTISWITCH_DOWN2 || ACT9_MULTISWITCH_DOWN3 || ACT9_MULTISWITCH_DOWN4
volatile uint8_t Act9 = Action9.Pos();
#endif 
#if not defined ACT10_MULTISWITCH || ACT10_MULTISWITCH_UP1 || ACT10_MULTISWITCH_UP2 || ACT10_MULTISWITCH_UP3 || ACT10_MULTISWITCH_UP4 || ACT10_MULTISWITCH_DOWN1 || ACT10_MULTISWITCH_DOWN2 || ACT10_MULTISWITCH_DOWN3 || ACT10_MULTISWITCH_DOWN4
volatile uint8_t Act10 = Action10.Pos();
#endif 
#if not defined ACT11_MULTISWITCH
volatile uint8_t Act11 = 5;
#endif 
#if not defined ACT12_MULTISWITCH || ACT12_MULTISWITCH_UP1 || ACT12_MULTISWITCH_UP2 || ACT12_MULTISWITCH_UP3 || ACT12_MULTISWITCH_UP4 || ACT12_MULTISWITCH_DOWN1 || ACT12_MULTISWITCH_DOWN2 || ACT12_MULTISWITCH_DOWN3 || ACT12_MULTISWITCH_DOWN4
volatile uint8_t Act12 = 0;
#endif 


static unsigned long timerOld;
unsigned long        loopTime;
unsigned long        timerLoop ;

static unsigned long timerOld2;
unsigned long        loopTime2;
unsigned long        timerLoop2 ;





volatile boolean Act1Permanent =false;
volatile boolean Act2Permanent =false;
volatile boolean Act3Permanent =false;
volatile boolean Act4Permanent =false;
volatile boolean Act5Permanent =false;
volatile boolean Act6Permanent =false;
volatile boolean Act7Permanent =false;
volatile boolean Act8Permanent =false;
volatile boolean Act9Permanent =false;
volatile boolean Act10Permanent =false;
volatile boolean Act11Permanent =false;
volatile boolean Act12Permanent =false;
volatile boolean Seq6Permanent =false;
volatile boolean Seq6bPermanent =false;
volatile boolean Seq7Permanent =false;
volatile boolean Seq7bPermanent =false;
volatile boolean Seq1Permanent =false;
volatile boolean Seq1bPermanent =false;
volatile boolean Seq2Permanent =false;
volatile boolean Seq2bPermanent =false;
////////////////////////////////////
volatile boolean Act11A_UpPermanent =false;
volatile boolean Act11A_DownPermanent =false;
volatile boolean Act11B_UpPermanent =false;
volatile boolean Act11B_DownPermanent =false;
volatile boolean Act11C_UpPermanent =false;
volatile boolean Act11C_DownPermanent =false;
volatile boolean Act11D_UpPermanent =false;
volatile boolean Act11D_DownPermanent =false;




#ifdef ACT1_MULTISWITCH
volatile boolean Act1 = false;
#endif 
#ifdef ACT2_MULTISWITCH
volatile boolean Act2 = false;
#endif 
#ifdef ACT3_MULTISWITCH
volatile boolean Act3 = false;
#endif 
#ifdef ACT4_MULTISWITCH
volatile boolean Act4 = false;
#endif 
#ifdef ACT5_MULTISWITCH
volatile boolean Act5 = false;
#endif 
#ifdef ACT6_MULTISWITCH
volatile boolean Act6 = false;
#endif 
#ifdef ACT7_MULTISWITCH
volatile boolean Act7 = false;
#endif 
#ifdef ACT8_MULTISWITCH
volatile boolean Act8 = false;
#endif 
#ifdef ACT9_MULTISWITCH
volatile boolean Act9 = false;
#endif 
#ifdef ACT10_MULTISWITCH
volatile boolean Act10 = false;
#endif 
#ifdef ACT11_MULTISWITCH
volatile boolean Act11 = false;
#endif 
#ifdef ACT12_MULTISWITCH
volatile boolean Act12 = false;
#endif 

#ifdef SEQ1_MULTISWITCH
volatile boolean Seq1 = false;
#endif 
#ifdef SEQ1B_MULTISWITCH
volatile boolean Seq1b = false;
#endif 
#ifdef SEQ2_MULTISWITCH
volatile boolean Seq2 = false;
#endif 
#ifdef SEQ2B_MULTISWITCH
volatile boolean Seq2b = false;
#endif 

#ifdef SEQ6_MULTISWITCH
volatile boolean Seq6 = false;
#endif 
#ifdef SEQ6B_MULTISWITCH
volatile boolean Seq6b = false;
#endif 
#ifdef SEQ7_MULTISWITCH
volatile boolean Seq7 = false;
#endif 
#ifdef SEQ7B_MULTISWITCH
volatile boolean Seq7b = false;
#endif 

#ifdef ACTION11A_UP_MULTISWITCH
volatile boolean Act11A_UP = false;
#endif 
#ifdef ACTION11A_DOWN_MULTISWITCH
volatile boolean Act11A_DOWN = false;
#endif 
#ifdef ACTION11B_UP_MULTISWITCH
volatile boolean Act11B_UP = false;
#endif 
#ifdef ACTION11B_DOWN_MULTISWITCH
volatile boolean Act11B_DOWN = false;
#endif 
#ifdef ACTION11C_UP_MULTISWITCH
volatile boolean Act11C_UP = false;
#endif 
#ifdef ACTION11C_DOWN_MULTISWITCH
volatile boolean Act11C_DOWN = false;
#endif 
#ifdef ACTION11D_UP_MULTISWITCH
volatile boolean Act11D_UP = false;
#endif 
#ifdef ACTION11D_DOWN_MULTISWITCH
volatile boolean Act11D_DOWN = false;
#endif 


#ifdef ACT1_MULTISWITCH_UP1
volatile boolean Act1= false;
#endif 
#ifdef ACT2_MULTISWITCH_UP1
volatile boolean Act2= false;
#endif
#ifdef ACT3_MULTISWITCH_UP1
volatile boolean Act3= false;
#endif
#ifdef ACT4_MULTISWITCH_UP1
volatile boolean Act4= false;
#endif
#ifdef ACT5_MULTISWITCH_UP1
volatile boolean Act5= false;
#endif
#ifdef ACT6_MULTISWITCH_UP1
volatile boolean Act6= false;
#endif
#ifdef ACT7_MULTISWITCH_UP1
volatile boolean Act7= false;
#endif
#ifdef ACT8_MULTISWITCH_UP1
volatile boolean Act8= false;
#endif
#ifdef ACT9_MULTISWITCH_UP1
volatile boolean Act9= false;
#endif
#ifdef ACT10_MULTISWITCH_UP1
volatile boolean Act10= false;
#endif
#ifdef ACT11A_UP_MULTISWITCH_UP1
volatile boolean Act11A_UP= false;
#endif
#ifdef ACT11A_DOWN_MULTISWITCH_UP1
volatile boolean Act11A_DOWN= false;
#endif
#ifdef ACT11B_UP_MULTISWITCH_UP1
volatile boolean Act11B_UP= false;
#endif
#ifdef ACT11B_DOWN_MULTISWITCH_UP1
volatile boolean Act11B_DOWN= false;
#endif
#ifdef ACT11C_UP_MULTISWITCH_UP1
volatile boolean Act11C_UP= false;
#endif
#ifdef ACT11C_DOWN_MULTISWITCH_UP1
volatile boolean Act11C_DOWN= false;
#endif
#ifdef ACT11D_UP_MULTISWITCH_UP1
volatile boolean Act11D_UP= false;
#endif
#ifdef ACT11D_DOWN_MULTISWITCH_UP1
volatile boolean Act11D_DOWN= false;
#endif

#ifdef ACT1_MULTISWITCH_UP2
volatile boolean Act1= false;
#endif 
#ifdef ACT2_MULTISWITCH_UP2
volatile boolean Act2= false;
#endif
#ifdef ACT3_MULTISWITCH_UP2
volatile boolean Act3= false;
#endif
#ifdef ACT4_MULTISWITCH_UP2
volatile boolean Act4= false;
#endif
#ifdef ACT5_MULTISWITCH_UP2
volatile boolean Act5= false;
#endif
#ifdef ACT6_MULTISWITCH_UP2
volatile boolean Act6= false;
#endif
#ifdef ACT7_MULTISWITCH_UP2
volatile boolean Act7= false;
#endif
#ifdef ACT8_MULTISWITCH_UP2
volatile boolean Act8= false;
#endif
#ifdef ACT9_MULTISWITCH_UP2
volatile boolean Act9= false;
#endif
#ifdef ACT10_MULTISWITCH_UP2
volatile boolean Act10= false;
#endif
#ifdef ACT11A_UP_MULTISWITCH_UP2
volatile boolean Act11A_UP= false;
#endif
#ifdef ACT11A_DOWN_MULTISWITCH_UP2
volatile boolean Act11A_DOWN= false;
#endif
#ifdef ACT11B_UP_MULTISWITCH_UP2
volatile boolean Act11B_UP= false;
#endif
#ifdef ACT11B_DOWN_MULTISWITCH_UP2
volatile boolean Act11B_DOWN= false;
#endif
#ifdef ACT11C_UP_MULTISWITCH_UP2
volatile boolean Act11C_UP= false;
#endif
#ifdef ACT11C_DOWN_MULTISWITCH_UP2
volatile boolean Act11C_DOWN= false;
#endif
#ifdef ACT11D_UP_MULTISWITCH_UP2
volatile boolean Act11D_UP= false;
#endif
#ifdef ACT11D_DOWN_MULTISWITCH_UP2
volatile boolean Act11D_DOWN= false;
#endif
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
void loop()
{
timerOld = micros();

#if defined SBUS_COMMUNICATION
  readSbusCommands(); // SBUS communication (pin 36)
#elif defined PPM_COMMUNICATION
  readPpmCommands(); // PPM communication (pin 34)
#else
  //  measure RC signals mark space ratio
  readRcSignals();

#endif
  
  steering();
  trigger();
  Servos(); 
  Initialisation();
  volumeControl();
  Sequences();
  Multiswitch();
  DacAudio.FillBuffer();
  SlowMotionServo::update(); /* actualisation de la position */
  ScheduleTable::update();

  

  timerLoop = micros();
  loopTime = timerLoop - timerOld ;


}

//
// =======================================================================================================
// 1st MAIN TASK, RUNNING ON CORE 0 (Interrupts are running on this core as well)
// =======================================================================================================
//

void Task1code(void *pvParameters)
{
  for (;;)
  {
  

    timerOld2 = micros();
    ledOff(); 
    // DAC offset fader
    dacOffsetFade();

    // Map pulsewidth to throttle
    mapThrottle();

    // Simulate engine mass, generate RPM signal
    engineMassSimulation();

    // Switch engine on or off
    engineOnOff();

    // LED control
    led();
    Action();
    esc();
    triggerSound();
    Radar();
    MotorTwo();
   


   

    timerLoop2 = micros();

   loopTime2 = timerLoop2 - timerOld2 ;
   

  }
}

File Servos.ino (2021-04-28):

//
// =======================================================================================================
// 													SERVOS
// =======================================================================================================
//

void Servos()

{

//if (Init) {
     
 /*  

    static unsigned long lastStateTime;

     if (millis() - lastStateTime > 100)     // Print the data every 300ms
      {
        lastStateTime = millis();
      Serial.println(manualServo);
      Serial.println(CH4.momentaryPos());
     
  
    
     
 
             
      }


*/
      
 

    #ifdef ACTION2_ENABLE
     #ifdef ANCHORMOTOR

        #ifdef ANCHORMOTOR_1
    if (Mouillage && !AncreBas) {
      
      Servo1.writeMicroseconds(AnchorSpeedDown);
    } else if (!Mouillage && AncreBas) {
      Servo1.writeMicroseconds(AnchorSpeedUp);
    }

    if (AncreStop) {

      Servo1.writeMicroseconds(1500);
      AnchorSpeedDown = 1600;
      AnchorSpeedUp = 1400;
    }
        #endif
        
      #ifdef ANCHORMOTOR_2
    if (Mouillage && !AncreBas) {
      
      Servo2.writeMicroseconds(AnchorSpeedDown);
    } else if (!Mouillage && AncreBas) {
      Servo2.writeMicroseconds(AnchorSpeedUp);
    }

    if (AncreStop) {

      Servo2.writeMicroseconds(1500);
      AnchorSpeedDown = 1600;
      AnchorSpeedUp = 1400;
    }
        #endif 

       #ifdef ANCHORMOTOR_3
    if (Mouillage && !AncreBas) {
      
      Servo3.writeMicroseconds(AnchorSpeedDown);
    } else if (!Mouillage && AncreBas) {
      Servo3.writeMicroseconds(AnchorSpeedUp);
    }

    if (AncreStop) {

      Servo3.writeMicroseconds(1500);
      AnchorSpeedDown = 1600;
      AnchorSpeedUp = 1400;
    }
        #endif 

         #ifdef ANCHORMOTOR_4
    if (Mouillage && !AncreBas) {
      
      Servo4.writeMicroseconds(AnchorSpeedDown);
    } else if (!Mouillage && AncreBas) {
      Servo4.writeMicroseconds(AnchorSpeedUp);
    }

    if (AncreStop) {

      Servo4.writeMicroseconds(1500);
      AnchorSpeedDown = 1600;
      AnchorSpeedUp = 1400;
    }
        #endif 

       #ifdef ANCHORMOTOR_5
    if (Mouillage && !AncreBas) {
      
      Servo5.writeMicroseconds(AnchorSpeedDown);
    } else if (!Mouillage && AncreBas) {
      Servo5.writeMicroseconds(AnchorSpeedUp);
    }

    if (AncreStop) {

      Servo5.writeMicroseconds(1500);
      AnchorSpeedDown = 1600;
      AnchorSpeedUp = 1400;
    }
        #endif 
         #ifdef ANCHORMOTOR_6
    if (Mouillage && !AncreBas) {
      
      Servo6.writeMicroseconds(AnchorSpeedDown);
    } else if (!Mouillage && AncreBas) {
      Servo6.writeMicroseconds(AnchorSpeedUp);
    }

    if (AncreStop) {

      Servo6.writeMicroseconds(1500);
      AnchorSpeedDown = ANCOR_SPEED_DOWN;
      AnchorSpeedUp = ANCOR_SPEED_UP;
    }
        #endif           
    
      #endif 
    #endif

   

  
	
#ifdef ACTION12_ENABLE

  #ifdef ACT12SERVOSWITCH

    if ((!engineOn && !manualServo &&!servoHome)) {
     
    #ifdef SERVO1_HOME
        if (servoPulse[1]<SERVO_START[1]){
          
          if (millis() - servoTime[1] > 10) {
            servoTime[1] = millis();
            servoPulse[1] += servoStep;
            if (servoPulse[1] > SERVO_START[1])
              servoPulse[1] = SERVO_START[1];
          }
        }
      
      
         else if (servoPulse[1]>SERVO_START[1]){
          
          if (millis() - servoTime[1] > 10) {
            servoTime[1] = millis();
            servoPulse[1] -= servoStep;
            if (servoPulse[1] < SERVO_START[1])
              servoPulse[1] = SERVO_START[1];
          }
        } 

        #endif 

        #ifdef SERVO2_HOME

        if (servoPulse[2]<SERVO_START[2]){
          
          if (millis() - servoTime[2] > 10) {
            servoTime[2] = millis();
            servoPulse[2] += servoStep;
            if (servoPulse[2] > SERVO_START[2])
              servoPulse[2] = SERVO_START[2];
          }
        }
      
      
         else if (servoPulse[2]>SERVO_START[2]){
          
          if (millis() - servoTime[2] > 10) {
            servoTime[2] = millis();
            servoPulse[2] -= servoStep;
            if (servoPulse[2] < SERVO_START[2])
              servoPulse[2] = SERVO_START[2];
          }
        } 

        #endif

        #ifdef SERVO3_HOME

        if (servoPulse[3]<SERVO_START[3]){
          
          if (millis() - servoTime[3] > 10) {
            servoTime[3] = millis();
            servoPulse[3] += servoStep;
            if (servoPulse[3] > SERVO_START[3])
              servoPulse[3] = SERVO_START[3];
          }
        }
      
      
         else if (servoPulse[3]>SERVO_START[3]){
          
          if (millis() - servoTime[3] > 10) {
            servoTime[3] = millis();
            servoPulse[3] -= servoStep;
            if (servoPulse[3] < SERVO_START[3])
              servoPulse[3] = SERVO_START[3];
          }
        } 

        #endif 
        #ifdef SERVO4_HOME

        if (servoPulse[4]<SERVO_START[4]){
          
          if (millis() - servoTime[4] > 10) {
            servoTime[4] = millis();
            servoPulse[4] += servoStep;
            if (servoPulse[4] > SERVO_START[4])
              servoPulse[4] = SERVO_START[4];
          }
        }
      
      
         else if (servoPulse[4]>SERVO_START[4]){
          
          if (millis() - servoTime[4] > 10) {
            servoTime[4] = millis();
            servoPulse[4] -= servoStep;
            if (servoPulse[4] < SERVO_START[4])
              servoPulse[4] = SERVO_START[4];
          }
        } 

        #endif
        #ifdef SERVO5_HOME

        if (servoPulse[5]<SERVO_START[5]){
          
          if (millis() - servoTime[5] > 10) {
            servoTime[5] = millis();
            servoPulse[5] += servoStep;
            if (servoPulse[5] > SERVO_START[5])
              servoPulse[5] = SERVO_START[5];
          }
        }
      
      
         else if (servoPulse[5]>SERVO_START[5]){
          
          if (millis() - servoTime[5] > 10) {
            servoTime[5] = millis();
            servoPulse[5] -= servoStep;
            if (servoPulse[5] < SERVO_START[5])
              servoPulse[5] = SERVO_START[5];
          }
        }

        #endif

        #ifdef SERVO6_HOME

        if (servoPulse[6]<SERVO_START[6]){
          
          if (millis() - servoTime[6] > 10) {
            servoTime[6] = millis();
            servoPulse[6] += servoStep;
            if (servoPulse[6] > SERVO_START[6])
              servoPulse[6] = SERVO_START[6];
          }
        }
      
      
         else if (servoPulse[6]>SERVO_START[6]){
          
          if (millis() - servoTime[6] > 10) {
            servoTime[6] = millis();
            servoPulse[6] -= servoStep;
            if (servoPulse[6] < SERVO_START[6])
              servoPulse[6] = SERVO_START[6];
          }
        } 

        #endif
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

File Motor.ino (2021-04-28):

//
// =======================================================================================================
// RADAR : Led11 = 5v_UBEC  Led10 = 5V
// =======================================================================================================
//


void Radar()
{
  if (MotorOn)
  {
    Motor1.On(11);
  }
  else
  {
    Motor1.Off(11);
  }
}

//
// =======================================================================================================
// MOTOR2 Led10 = 5v_UBEC  Led10 = 5V
// =======================================================================================================
//

void MotorTwo()

{

  if (Seq1LedPart1OnOff) {

#ifdef SEQ1_MOTOR2_PART1
    Motor2.On(10);
#endif

  }

  else if (!Seq1LedPart1OnOff && !Seq2LedPart1OnOff) {

#ifdef SEQ1_MOTOR2_PART1
    Motor2.Off(10);
#endif



  }

  if (Seq1LedPart2OnOff) {

#ifdef SEQ1_MOTOR2_PART2
    Motor2.On(10);
#endif

  }

  else if (!Seq1LedPart2OnOff && !Seq2LedPart2OnOff) {

#ifdef SEQ1_MOTOR2_PART2
    Motor2.Off(10);
#endif


  }
  if (Seq1LedPart3OnOff) {

#ifdef SEQ1_MOTOR2_PART3
    Motor2.On(10);
#endif

  }

  else if (!Seq1LedPart3OnOff && !Seq2LedPart3OnOff) {

#ifdef SEQ1_MOTOR2_PART3
    Motor2.Off(10);
#endif



  }

  if (Seq1LedPart4OnOff) {

#ifdef SEQ1_MOTOR2_PART4
    Motor2.On(10);
#endif

  }

  else if (!Seq1LedPart4OnOff && !Seq2LedPart4OnOff) {

#ifdef SEQ1_MOTOR2_PART4
    Motor2.Off(10);
#endif


  }

  if (Seq2LedPart1OnOff) {

#ifdef SEQ2_MOTOR2_PART1
    Motor2.On(10);
#endif

  }

  else if (!Seq1LedPart1OnOff && !Seq2LedPart1OnOff) {

#ifdef SEQ2_MOTOR2_PART1
    Motor2.Off(10);
#endif



  }

  if (Seq2LedPart2OnOff) {

#ifdef SEQ2_MOTOR2_PART2
    Motor2.On(10);
#endif

  }

  else if (!Seq1LedPart2OnOff && !Seq2LedPart2OnOff) {

#ifdef SEQ2_MOTOR2_PART2
    Motor2.Off(10);
#endif


  }
  if (Seq2LedPart3OnOff) {

#ifdef SEQ2_MOTOR2_PART3
    Motor2.On(10);
#endif

  }

  else if (!Seq1LedPart3OnOff && !Seq2LedPart3OnOff) {

#ifdef SEQ2_MOTOR2_PART3
    Motor2.Off(10);
#endif



  }

  if (Seq2LedPart4OnOff) {

#ifdef SEQ2_MOTOR2_PART4
    Motor2.On(11);
#endif

  }

  else if (!Seq1LedPart4OnOff && !Seq2LedPart4OnOff) {

#ifdef SEQ2_MOTOR2_PART4
    Motor2.Off(11);
#endif


  }



  if (Seq10LedPart1OnOff) {

#ifdef SEQ1B_MOTOR2_PART1
    Motor2.On(11);
#endif

  }

  else if (!Seq10LedPart1OnOff && !Seq20LedPart1OnOff) {

#ifdef SEQ1B_MOTOR2_PART1
    Motor2.Off(11);
#endif



  }

  if (Seq10LedPart2OnOff) {

#ifdef SEQ1B_MOTOR2_PART2
    Motor2.On(11);
#endif

  }

  else if (!Seq10LedPart2OnOff && !Seq20LedPart2OnOff) {

#ifdef SEQ1B_MOTOR2_PART2
    Motor2.Off(11);
#endif


  }
  if (Seq10LedPart3OnOff) {

#ifdef SEQ1B_MOTOR2_PART3
    Motor2.On(11);
#endif

  }

  else if (!Seq10LedPart3OnOff && !Seq20LedPart3OnOff) {

#ifdef SEQ1B_MOTOR2_PART3
    Motor2.Off(11);
#endif



  }

  if (Seq10LedPart4OnOff) {

#ifdef SEQ1B_MOTOR2_PART4
    Motor2.On(11);
#endif

  }

  else if (!Seq10LedPart4OnOff && !Seq20LedPart4OnOff) {

#ifdef SEQ1B_MOTOR2_PART4
    Motor2.Off(11);
#endif


  }

  if (Seq20LedPart1OnOff) {

#ifdef SEQ2B_MOTOR2_PART1
    Motor2.On(11);
#endif

  }

  else if (!Seq10LedPart1OnOff && !Seq20LedPart1OnOff) {

#ifdef SEQ2_MOTOR2_PART1
    Motor2.Off(11);
#endif



  }

  if (Seq20LedPart2OnOff) {

#ifdef SEQ2B_MOTOR2_PART2
    Motor2.On(11);
#endif

  }

  else if (!Seq10LedPart2OnOff && !Seq20LedPart2OnOff) {

#ifdef SEQ2B_MOTOR2_PART2
    Motor2.Off(11);
#endif


  }
  if (Seq20LedPart3OnOff) {

#ifdef SEQ2B_MOTOR2_PART3
    Motor2.On(11);
#endif

  }

  else if (!Seq10LedPart3OnOff && !Seq20LedPart3OnOff) {

#ifdef SEQ2B_MOTOR2_PART3
    Motor2.Off(11);
#endif



  }

  if (Seq20LedPart4OnOff) {

#ifdef SEQ2B_MOTOR2_PART4
    Motor2.On(11);
#endif

  }

  else if (!Seq10LedPart4OnOff && !Seq20LedPart4OnOff) {

#ifdef SEQ2B_MOTOR2_PART4
    Motor2.Off(11);
#endif


  }




}

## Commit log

2022-10-18 Update Sound.ino
    bug with action 3
    [Sound.ino]
2022-10-18 Update Action.ino
    bug multiswitch action 8
    [Action.ino]
